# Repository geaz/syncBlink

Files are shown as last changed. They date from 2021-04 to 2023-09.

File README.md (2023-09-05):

   


# syncBlink
**syncBlink** is a lighting system that offers WiFi connectivity, programmability, and responsiveness to music. It enables users to create their own unique light patterns through customizable scripts. To facilitate this, the syncBlink Hub is equipped with a dedicated web application that allows users to write and control these scripts effectively.

In addition, the **syncBlink Hub** initiates a simple mesh network that includes a specialized TCP server. By connecting to this mesh network, **syncBlink Nodes** can establish an additional access point for other nodes to connect to. This means that even if certain nodes are out of range from the **syncBlink Hub**, they can still join the mesh network as long as at least one node is within range. These nodes have the ability to receive messages generated by the hub.

*Combining all these features, it becomes possible to create a synchronized mesh network of WiFi-connected devices that dynamically react to music.*

# State of the Project

This project is considered done. Creating it was a great experience overall. Especially creating the custom script language for the ESP8266 which works pretty great, considering the limitations of the ESP8266. The project implements a complete custom script language, a web application to create, compile and save the scripts, and a VM to execute the compiled scripts. All of this within the available 80kB RAM on the ESP8266.

It still has some flaws (for example the UDP Discovery does not work sometimes) and I still have ideas in mind for this project, but I already spend many hours and days on this project and have to move on. 

# 📖 Table of Contents
1. [🏠 syncBlink Hub](#-syncBlink-Hub)
2. [🌲 syncBlink Node](#-syncBlink-Node)
3. [🚀 Web Application](#-web-application)
4. [🧑‍💻 blinkScript - syncBlink Script Language](#-blinkScript)

## 🏠 syncBlink Hub

The hub is the central part of a **syncBlink** mesh. It provides a web application to manage the mesh and to create and edit **blinkScript**s.

Using the provided 3D models in the *stl* folder, designed in Fusion 360, you can easily bring your **syncBlink Hub** to life. The STL files in the repository make printing the necessary parts a snap. For customizations the Fusion 360 archives files are also provided in the *cad* folder.

The repository tries to provide a clear instruction to give a smooth assembly experience.
Flashing the firmware onto the used Wemos D1 Mini is made simple with using Visual Studio Code and PlatformIO.

Please head over to the **[syncBlink Hub](README%20Station.md)** readme for more information how to build and flash a hub device.

## 🌲 syncBlink Node

The **syncBlink Hub** is just the start. To create a larger mesh of lights it is necessary to build one, two or three nodes (or even more). **syncBlink Nodes** are able to connect to the **syncBlink** mesh to form a larger and wireless light system. The nodes are able to come in any size or form.

Please head over to the **[syncBlink Node](README%20Node.md)** readme for more information how to build and flash your first node device.

## 🚀 Web Application

The **syncBlink Hub** exposes a web application for mobiles and desktop.
Just connect to the access point with the following password:

```
SyncBlinkSaysLetThereBeLight!
```

By visiting the web application on **http://192.168.1.1** with a mobile browser the hub will serve a *setting* page where you are able to configure a WiFi network. The hub will connect to this network during the start procedure.

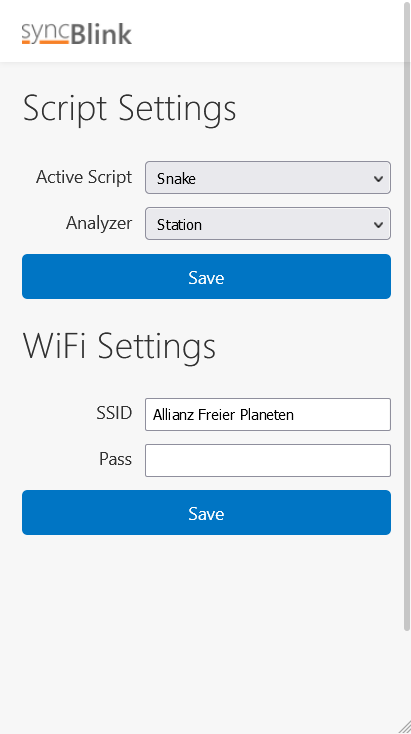
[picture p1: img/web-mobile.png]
syncBlink - Mobile


After the hub is connected to a network the hub IP will appear on the bottom right of the display. By visiting the hub web application with a desktop browser the hub serves an overview of the current **syncBlink Mesh**.

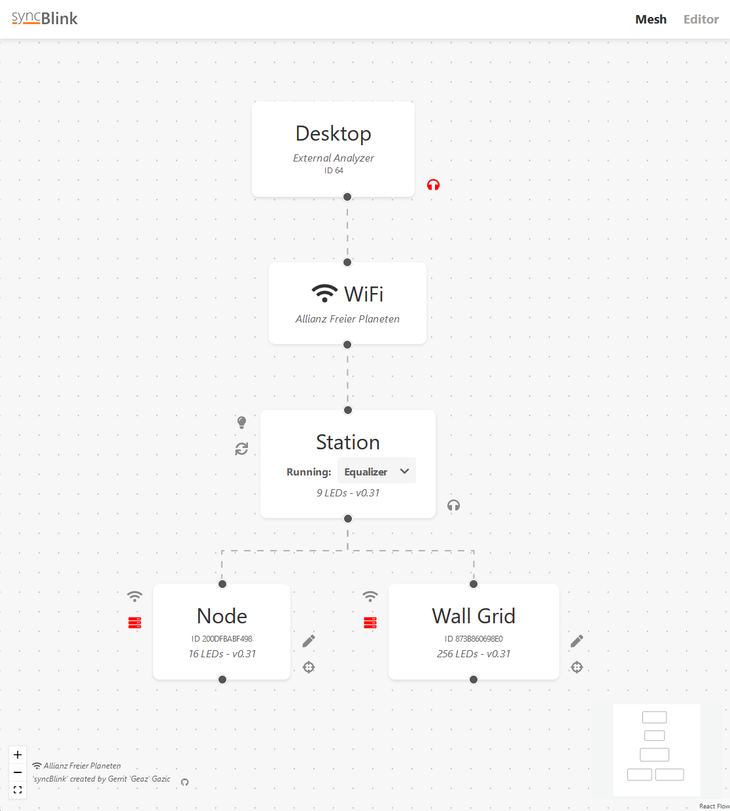
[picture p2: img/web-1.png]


The graph provides functions to a varity of different features. Like pinging nodes, switching the currently running scripts or changing the analyzer. Visit the *Editor* menu to change the content of the scripts on the hub or to create new ones.

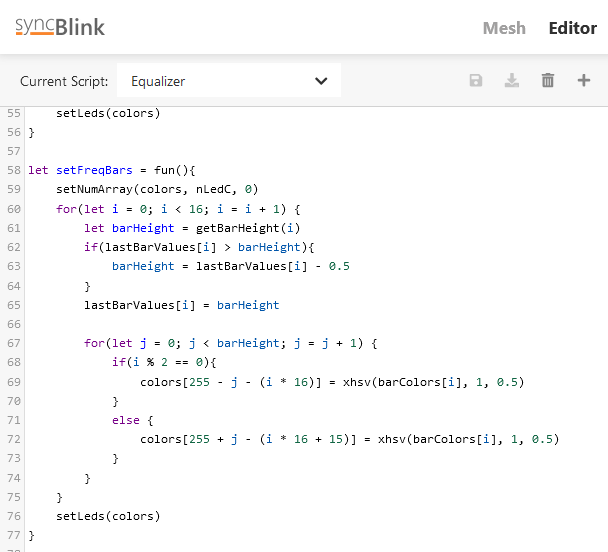
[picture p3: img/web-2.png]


**Info**
```
If you get random disconnections of your nodes after connecting your hub to a WiFi network,  
it is most probably because of an instable connection to the router. The problem is, that the  
ESP8266 just has one WiFi chip which is used to connect to the router AND serves as the access  
point for the nodes. If the hub looses the connection to the router, it can cause a disconnection  
of the access point clients.
```

## 🧑‍💻 blinkScript

**blinkScript** is a custom script language for **syncBlink**. The scripts get compiled by the web application and are stored in a byte code format on the **syncBlink Hub**. On selection the compiled script gets distributed in the mesh and gets execute by the integrated virtual machine on each node.

To make the script language possible on the esp8266 it has a few limitations which shouldn't affect to many scripts (like a limit of 256 objects per script).

The script language is pretty basic and comes with the following features:

- Functions
- Variables
- Conditionals (if/else - NO else if)
- for/while loops
- Arrays
- Closures
- Some build in functions and variables

### Available global variables

- **maxF** *The maximum frequency which is recognizable by syncBlink*
- **nLedC** *The LED count of the current node*
- **mLedC** *The LED count of the whole mesh*
- **pLedC** *The LED count of the current route position*
- **pNodeC** *The node count of the current route position*
- **lVol** *The last analyzed volume in percentage (0-100)*
- **lFreq** *The last analyzed frequency*
- **vol** *The current analyzed volume in percentage (0-100)*
- **freq** *The current analyzed frequency*
- **name** *The name of the current node (initialy specified by the flashed config.json)*
- **type** *The type name of the current node (specified by the flashed config.json)* 
- **freqBin** *An array holding 48 bins of the FFT analysis (power of the different frequencies). The bin resolution is round about 100mHz*       

### Available global functions

- **println(message: string)** *Prints the message to the serial output*
- **setNumArray(array: Array<number>, size: number, value: number)** *Function to quickly fill a numeric array of the given size with the given value. Helpful to reset or initialize an array*
- **setGroups(countPerGroup: number)** *Set the LEDs of the current node to groups of the provided size. For example, if the node has 16 LEDs and setGroups(4) is called, the node will handle the 16 LEDs like four LEDs, where always four LEDs will be grouped together as one.*
- **setLinearGroups(countPerGroup: number)** *Same as above, but the internal numbering of the LEDs will be sequential. Resulting in a different group pattern.*
- **clearGroups()** *Clears all defined groups.*
- **setDelay(analyzerCount: number)** *Delays the analyzer results by the given amount of updates.*
- **getLed(led: number)** *Gets the color (Hex RGB) of the given LED.*
- **setLeds(colors: Array<number>)** *Set LEDs by defining an array of Hex colors.*
- **setAllLeds(color: number)** *Sets all LEDs to the given color (Hex RGB).*
- **map(value: number, inMin: number, inMax: number, outMin: number, outMax: number)** *Maps the value within the range of inMin and inMax to the new range defined by outMin and outMax.*
- **xrgb(r: number, g: number, b: number)** *Converts the given RGB color to a hex number representation.*
- **xhsv(h: number, s: number, v: number)** *Converts the given HSV color to a hex number representation.*

### Minimal example script

Each script has to define two functions as given in the following example.

```
let update = fun(delta) {
    // This function gets executed on each analyzer result (loop)
    // 'delta' contains the milliseconds since the last call of the loop
}

let init = fun(){
    // this function gets executed ONCE at start of the script
}
```

The **syncBlink Hub** comes with some example scripts. Also available [here](src/firmware/data/scripts/).

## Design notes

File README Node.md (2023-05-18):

   


# syncBlink Node
**syncBlink Node**s are devices which are able to connect to the *tcp server* provided by the **syncBlink Hub** or a closer available other *node* via WiFi. Because every *node* is also an access point and a tcp server it is possible to span a pretty big mesh of nodes.

This repository provides a simple example for a **syncBlink Node**. But it is possible to create other devices like for example wall mounted LED devices which will connect to the **syncBlink Hub** to create some nice color effects. Or desk lamp like devices. Just play with your imagination and come up with some cool devices. All you have to do is to take a *Wemos D1 Mini* connect some LEDs and flash the *node* firmware on it.

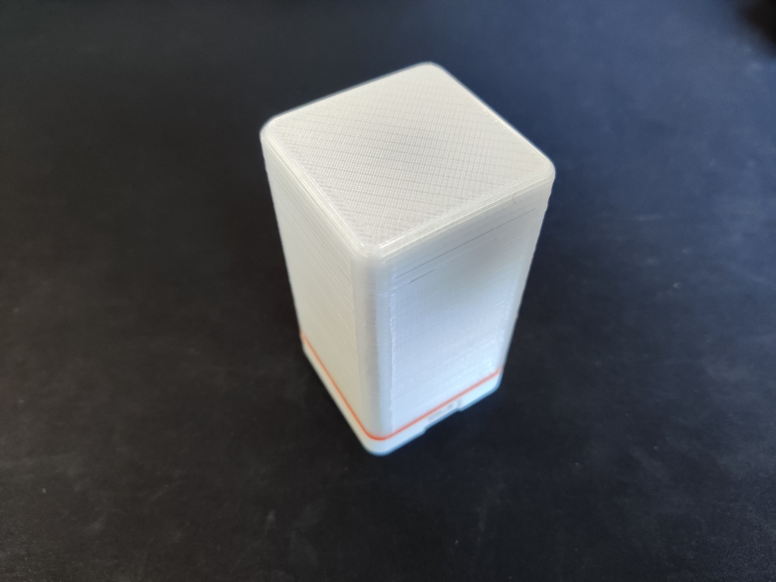
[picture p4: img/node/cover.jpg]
syncBlink - Cover


## BOM

- 3D Printed Parts
- Wemos D1 Mini
- 1x 330 Ohm Resistor
- [4x4 WS2812B LEDs (I used a strip and cut it)](https://www.amazon.de/dp/B01CDTED80)
- 4x M2x12mm screws
- Wire

## Firmware

To flash the firmware onto the Wemos connect it to your PC and press the *Upload* button in the status bar.

syncBlink - Flash

Each node also needs a flashed file system. Primarly to create a *config.json* which contains the configuration for the specific node. Just use the platformIO tasks **Build Filesystem Image** and **Upload Filesystem Image**. PlatformIO will flash the complete content of the *data* folder.

To get a node running the *config.json* needs at least the following content:

```
{
    "name": "Node",   // Initial name of the node (can be changed through the web app)
    "type": "node",   // The type name of the node. Can be used to distinguish nodes in the scripts.
    "led_count": 16,  // Amount of LEDs connected to the node
    "is_node": true   // A flag that tells the firmware, that it runs on a node
}
```

This is the list of all available config keys.

```
{
    "name": "Node",
    "type": "nodeType",
    "led_count": 9,
    "is_hub": false,
    "is_node": true,
    "is_analyzer": false,
    "has_display": false,
    "active_script": "Snake",
    "wifi_ssid": "WIFI",
    "wifi_pw": "PW"
}
```

## Build

Insert the four led strips into the *middle* part. And solder them together - **keep the direction of the data line in mind!**

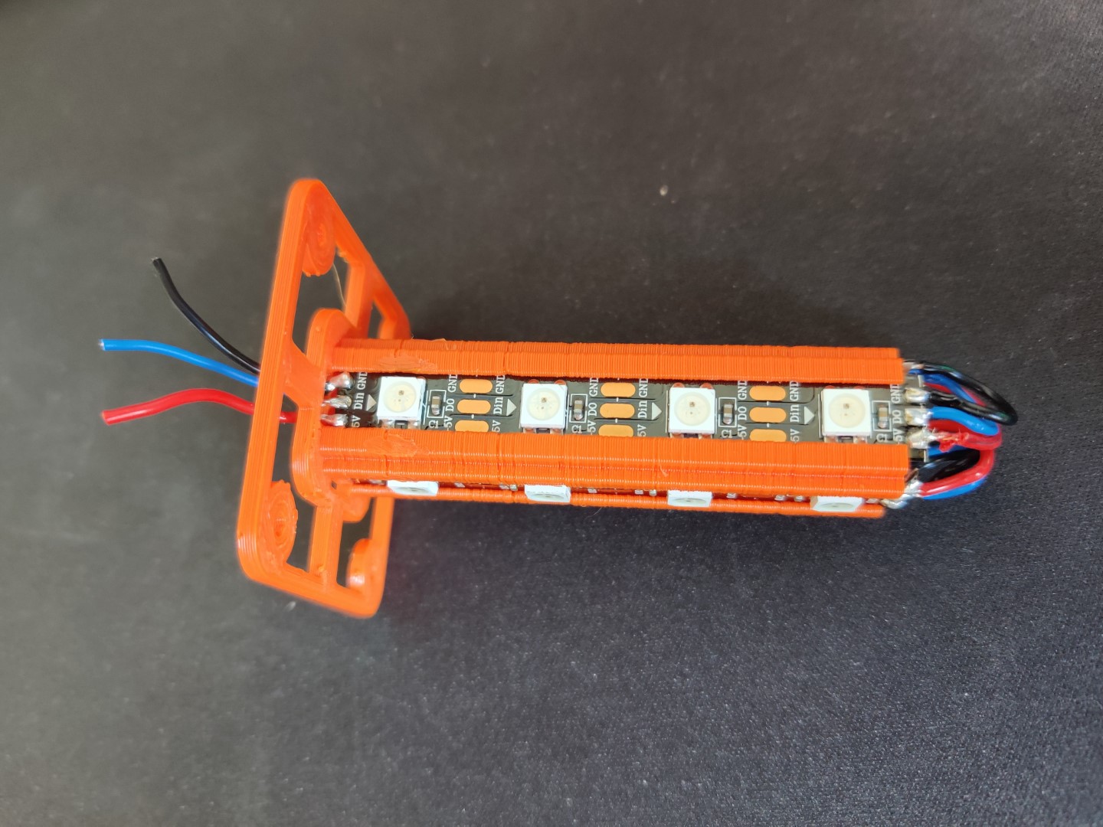
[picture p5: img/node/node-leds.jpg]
node-leds


Solder the LEDs to the *Wemos D1 Mini*. *VCC* to *5V*, *GND* to *GND* and *DataIn* to *D4*. Next, solder the 300Ohm resistor to the pins *RST* and *D0* and insert the *D1 Mini* into the *bottom* part.

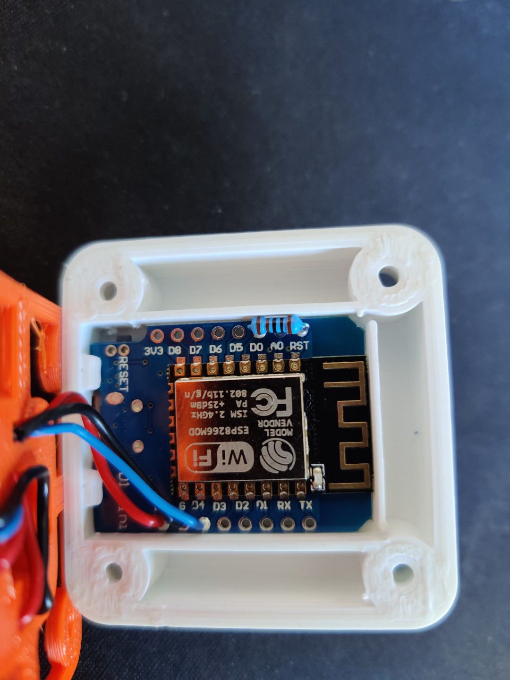
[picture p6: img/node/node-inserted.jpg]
node-inserted


Cut four pieces of paper and insert them into the slots of the *top* part.

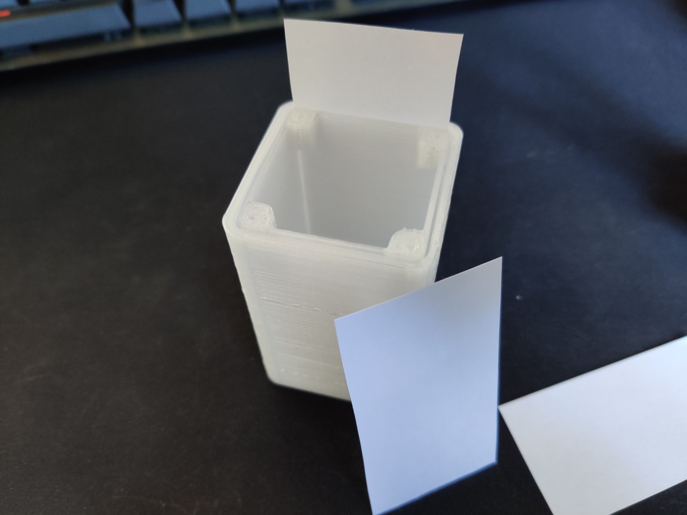
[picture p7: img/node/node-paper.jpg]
node-paper


Now place everything together and close it with the screws. You are done!

node-done

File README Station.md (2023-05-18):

   


# syncBlink Hub

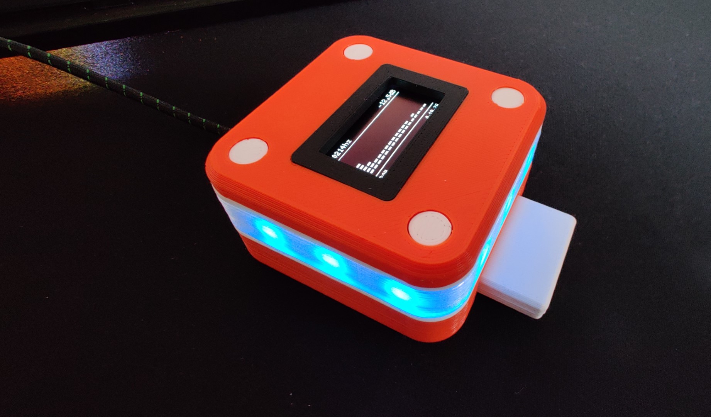
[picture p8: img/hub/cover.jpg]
syncBlink Hub


## Table of Contents
1. [🛥️ 3D Model](#-3d-model)
2. [📄 BOM](#-bom)  
3. [🚀 Firmware](#-firmware)  
4. [👷 Build](#-build)

### 🛥️ 3D Model
The models were designed in Fusion 360. The exported STLs are included in the Github repository (*stl* folder). Furthermore there are Fusion 360 archive files ready to download (*cad* folder).

### 📄 BOM

- 3D Printed Parts
- 1x Wemos D1 Mini
- 1x Capacitor 680uF
- 1x MAX4466
- [9x WS2812B LEDs (I used a strip and cut it)](https://www.amazon.de/dp/B01CDTED80)
- 4x M2x12mm screws
- 4x M3x4mm screws
- Wire
- Hotglue & Superglue

### 🚀 Firmware

Before building **syncBlink** you should flash the firmware onto the Wemos D1 Mini. This way you are able to make sure that it is functional. Open the project in [Visual Studio Code](https://code.visualstudio.com/). The project uses [PlatformIO](https://platformio.org/platformio-ide) to develop the firmware. Install the PlatformIO extension into Visual Studio Code, if not already done. 

To flash the firmware onto the Wemos connect it to your PC and press the *Upload* button in the status bar.

syncBlink - Flash

You also have to flash the file system to the Wemos.

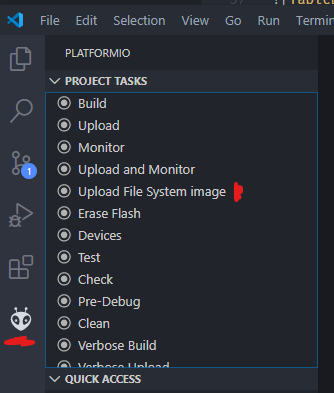
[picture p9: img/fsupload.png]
syncBlink - Filesystem


Afterwards start the *serial monitor* and you should see some outputs like in the screenshot below. If you are able to see the output, the device is working and you are ready to build the **syncBlink Hub**.

syncBlink - Serial

### 👷 Build

First of all, make yourself comfortable with the following schematics. It shows you all parts of the *Hub* which are necessary to connect to each other. We will use a piece of stripboard for each wire which is not directly connected to the Wemos D1 Mini. Mostly to provide power to each part.

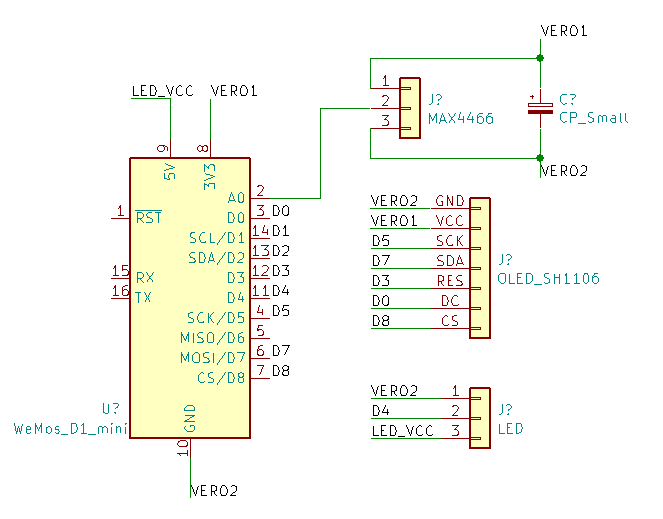
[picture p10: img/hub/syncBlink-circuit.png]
syncBlink - Schematics


Now that you made yourself comfortable with the wiring, take the *Top* part and the *Frame* and glue them together with the superglue. I recommend to place something heavy on top to make sure that they bond well.

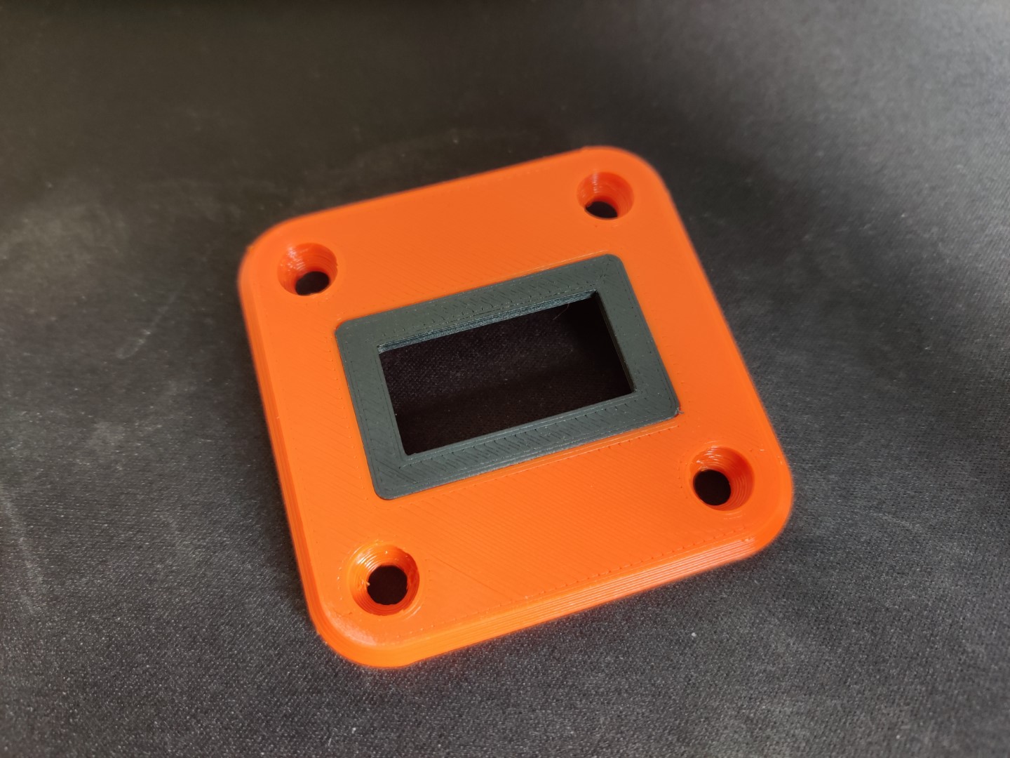
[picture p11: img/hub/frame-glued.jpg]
syncBlink - Frame Glued


Solder wires to your display and mount it to the *Top* part.

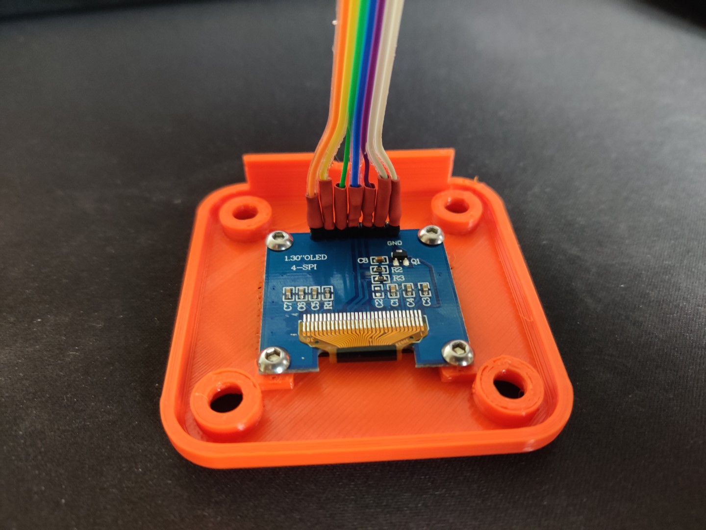
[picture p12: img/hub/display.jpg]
syncBlink - Display


To diffuse the LEDs a bit, the *middle* part has a small slot for a paper insert. Take a bit of paper and cut it into a narrow stripe and insert it into the slot.

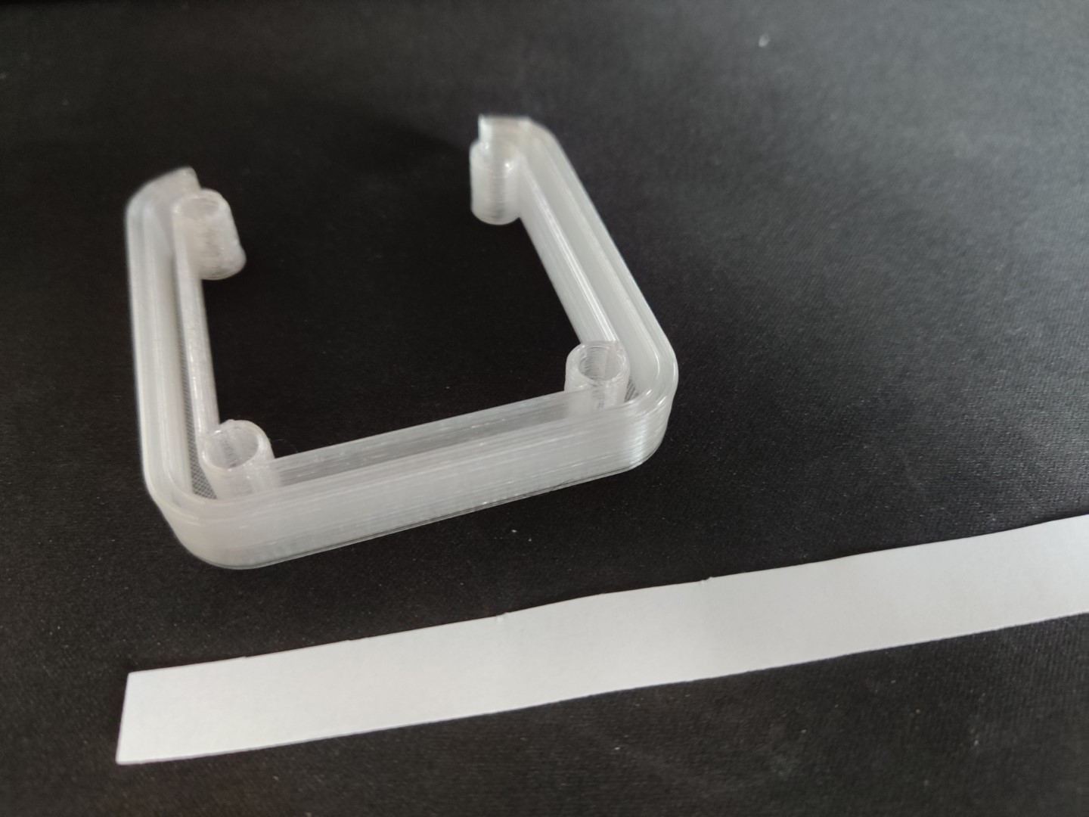
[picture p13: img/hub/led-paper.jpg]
syncBlink - LED Paper


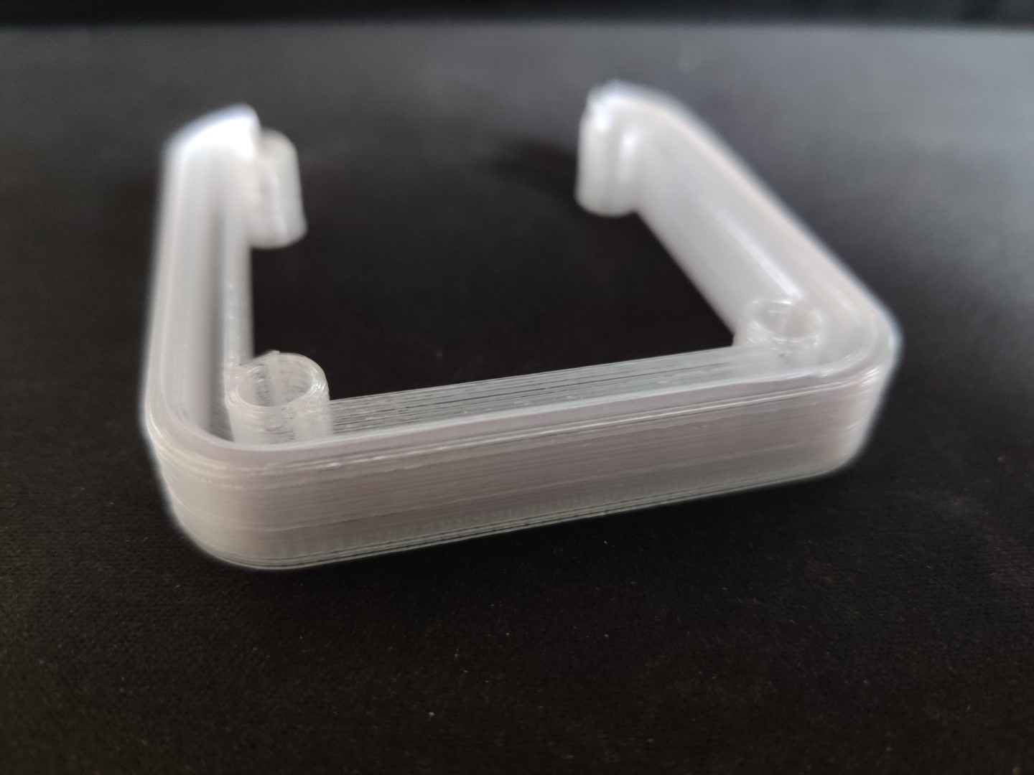
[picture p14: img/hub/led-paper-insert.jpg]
syncBlink - LED Paper Inserted


Solder three wires to your nine LED stripe and insert it into the *middle* part, too - **pay attention to the data line direction**. I bent the cables away from the back of the shell to avoid any possible interference between the microphone cables and the LEDs.

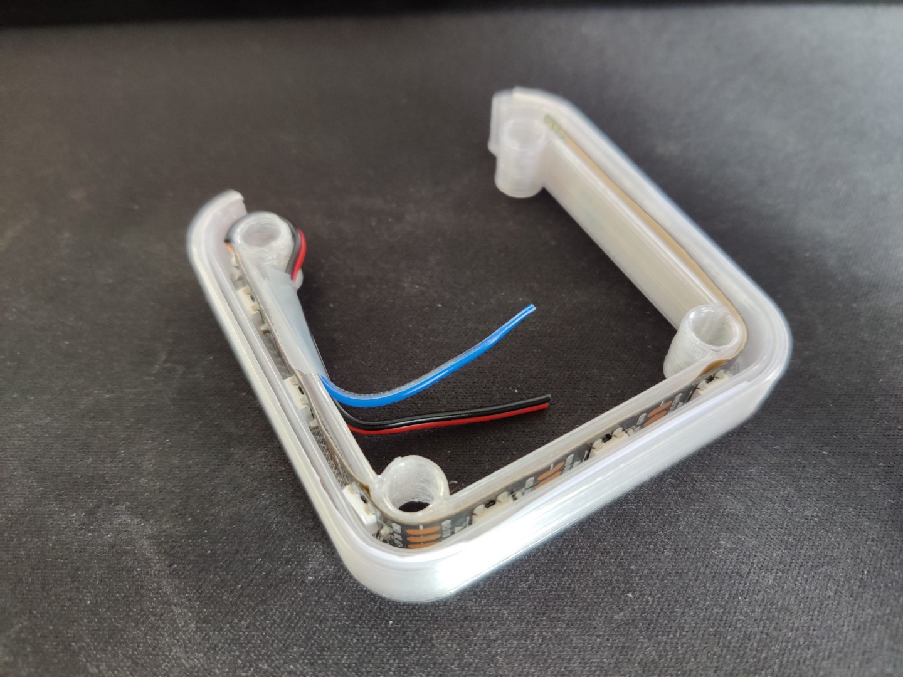
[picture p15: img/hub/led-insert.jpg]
syncBlink - LED Inserted


Solder three wires to your microphone and attach it with hotglue to the *Bottom* part of the shell.

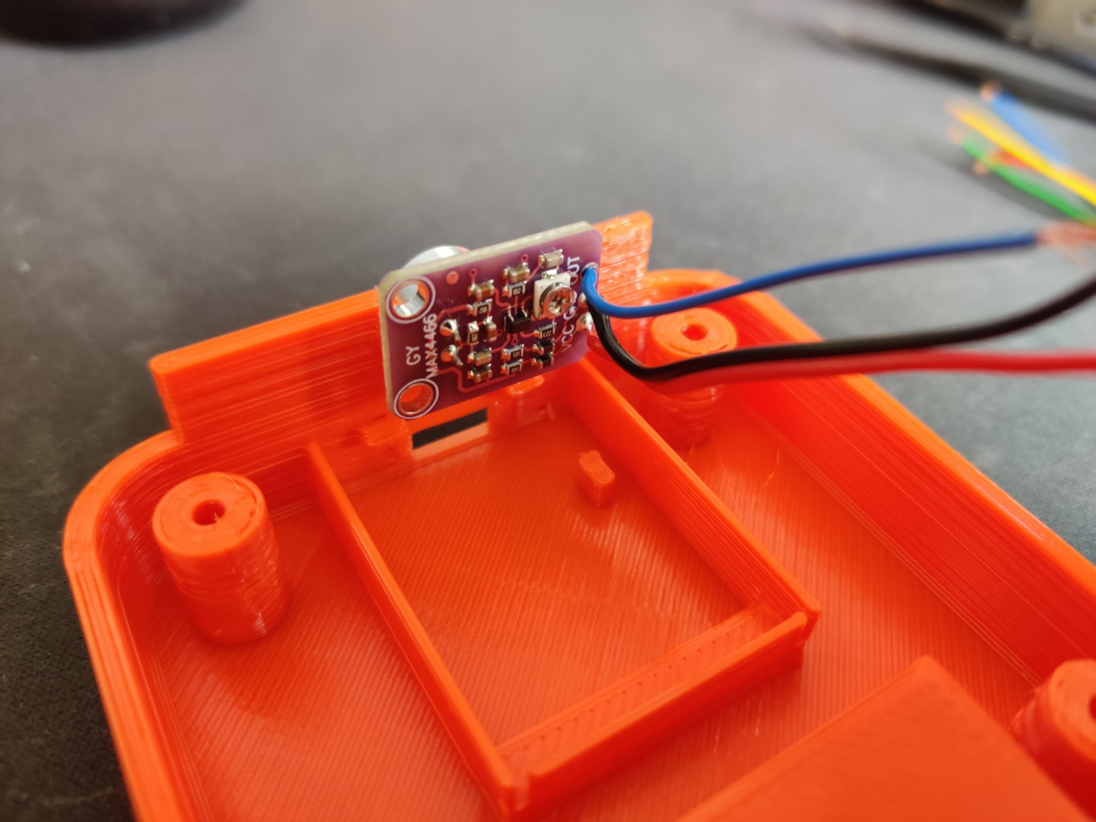
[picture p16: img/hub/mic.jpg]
syncBlink - Mic


Create a 2x7 sized piece out of the stripboard. Picture below as a reference - pay attention to the copper line directions.  
Solder all necessary components and wires as shown in the verboard image below and the schematics above. The ground wires are only indicated (read the red comment) to keep the image tidy.

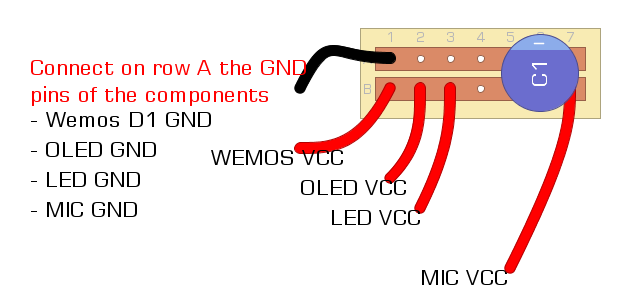
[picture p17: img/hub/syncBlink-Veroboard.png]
syncBlink - Veroboard


Mount the Wemos D1 Mini to the *Bottom* part of the shell.

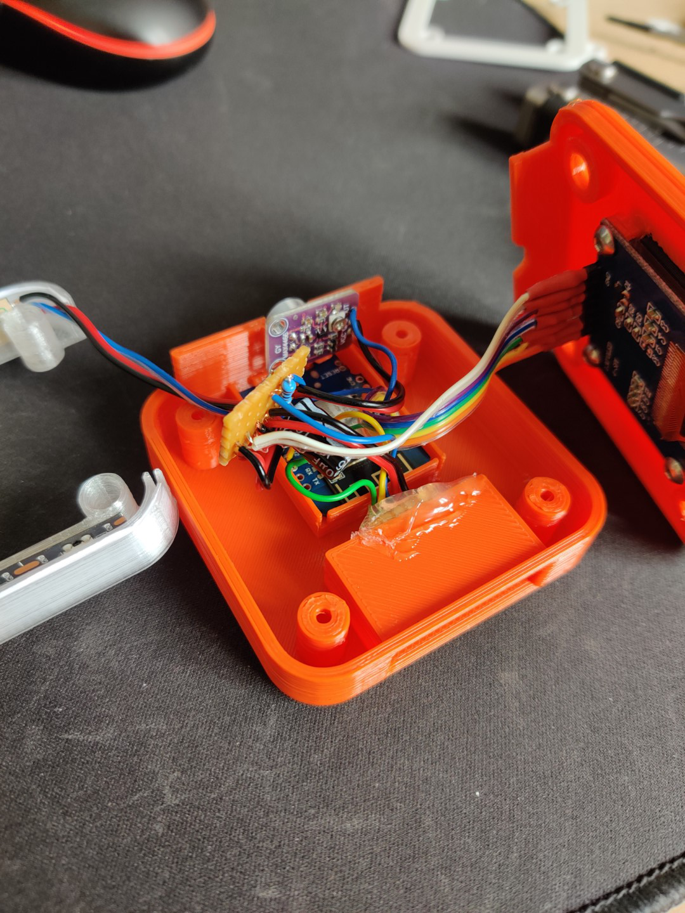
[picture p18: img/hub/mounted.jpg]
syncBlink - Mounted


All components should be connected and you should be able to power the Wemos. You will see the *decibel* in the top right of the display. Set the gain of you microphone with a small screwdriver. It should float between -40 and -43dB in a silent room. If done, place the stripboard into the shell, place one of the *divider* parts on top of the *bottom* part, then place the *middle* part on top of it. Followed by an additional *divider* and the *top* part.
Insert the *bolts* into the four holes and use the M2x12mm screws to close the shell. Your **syncBlink Hub** is done!

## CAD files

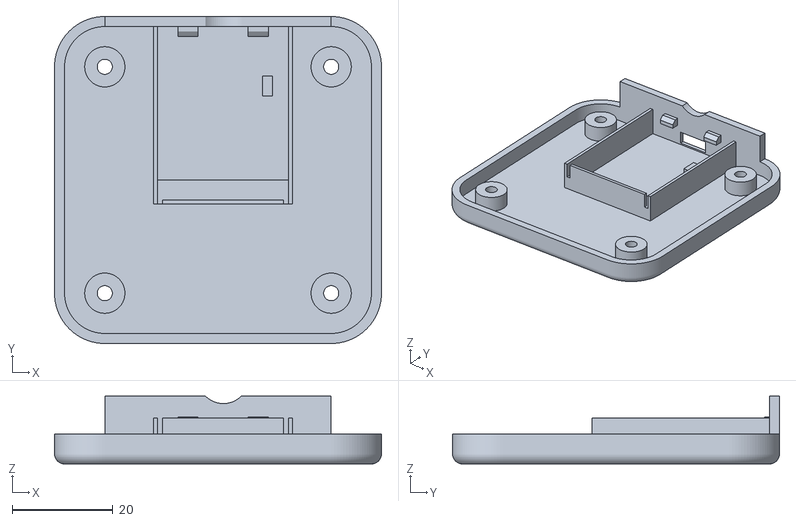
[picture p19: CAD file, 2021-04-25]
stl/hub/1x Bottom.stl
65.0 x 65.0 x 13.5

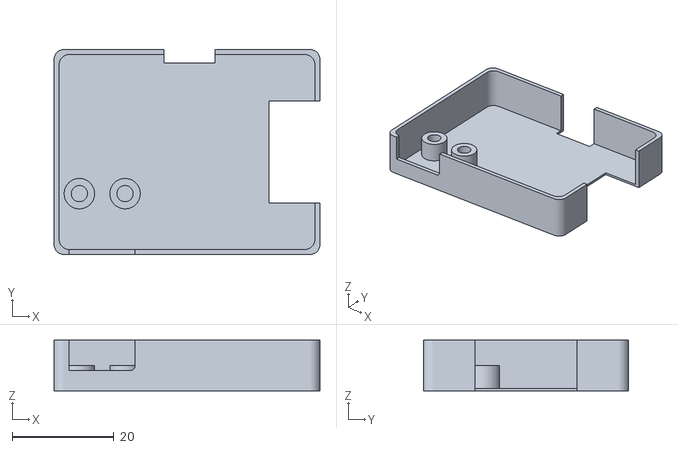
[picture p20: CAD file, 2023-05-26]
stl/matrix/Electronics Bottom (for powerstrips).stl
52.4 x 40.4 x 10.0

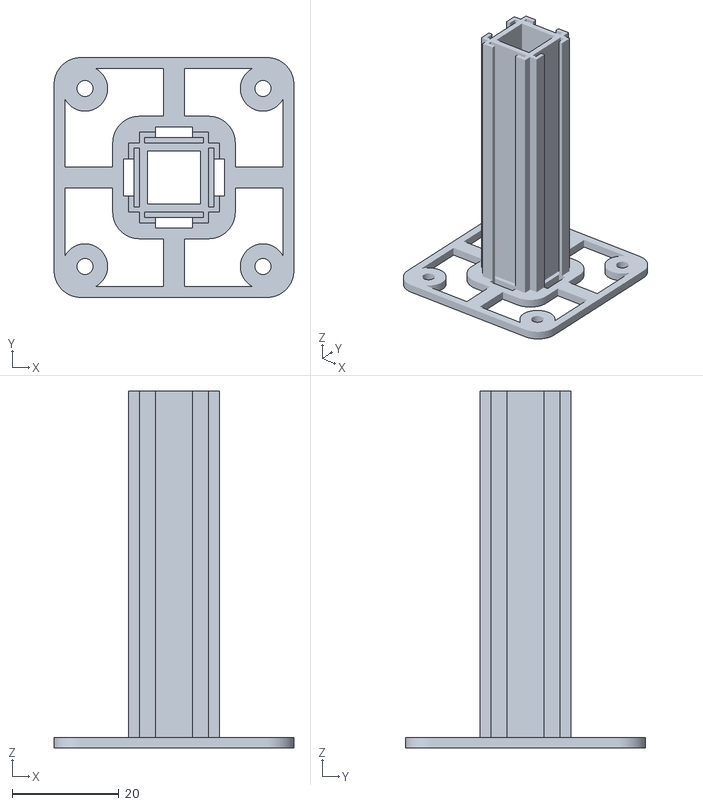
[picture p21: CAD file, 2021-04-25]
stl/node/Middle.stl
45.0 x 45.0 x 67.0

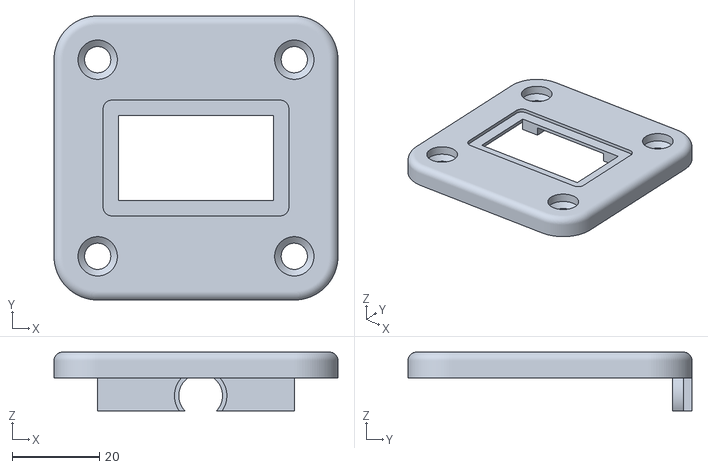
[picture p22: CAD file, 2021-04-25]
stl/hub/1x Top.stl
65.0 x 65.0 x 13.5

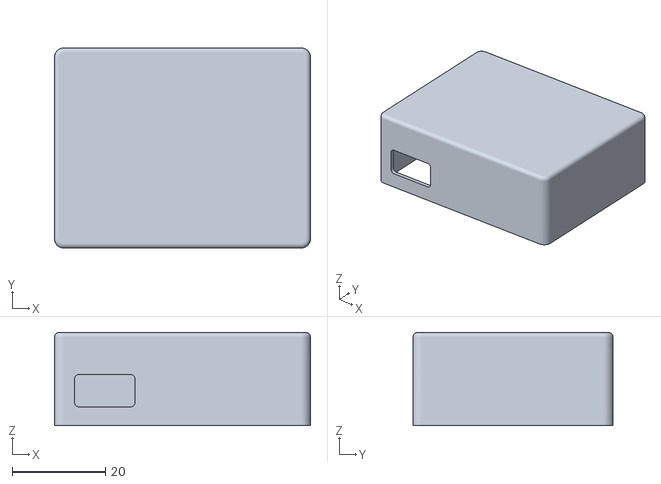
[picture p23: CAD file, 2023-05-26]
stl/matrix/Electronics Top.stl
55.0 x 43.0 x 20.0

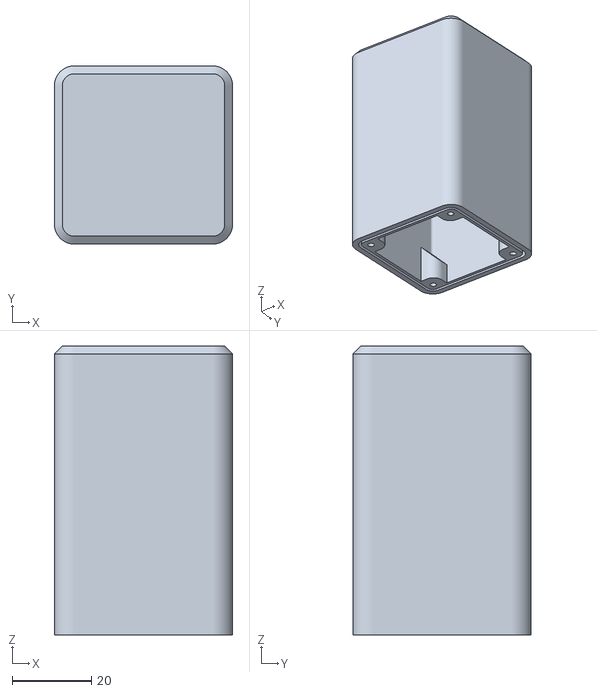
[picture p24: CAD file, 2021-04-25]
stl/node/Top.stl
45.0 x 45.0 x 73.0

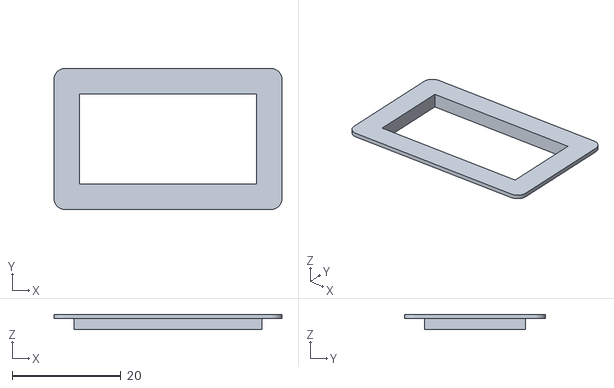
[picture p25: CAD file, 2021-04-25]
stl/hub/1x Frame.stl
41.9 x 25.9 x 2.80

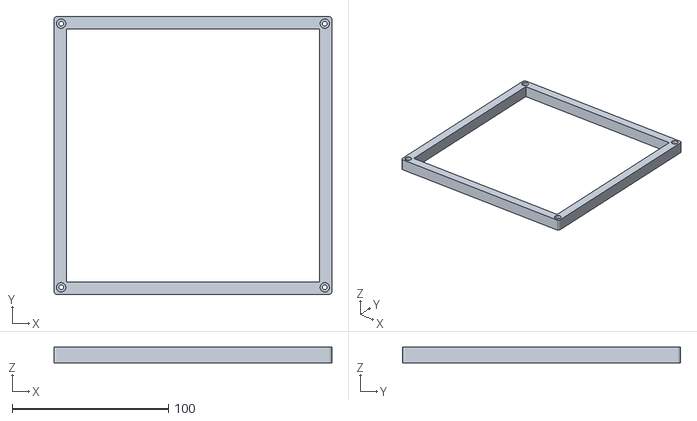
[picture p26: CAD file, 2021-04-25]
stl/matrix/Frame.stl
177.8 x 177.8 x 10.2

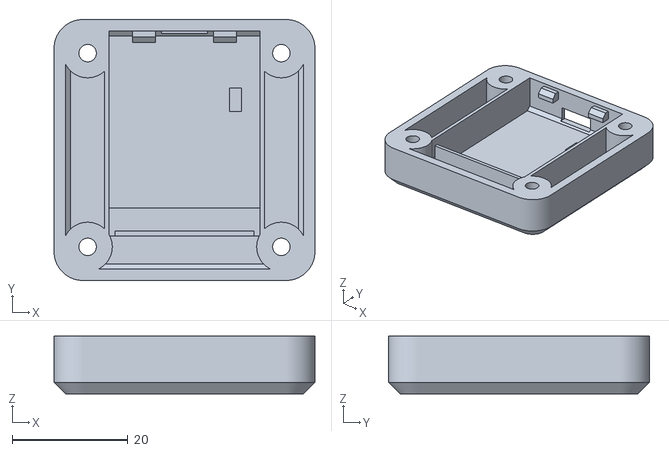
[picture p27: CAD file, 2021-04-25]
stl/node/Bottom.stl
45.0 x 45.0 x 10.0

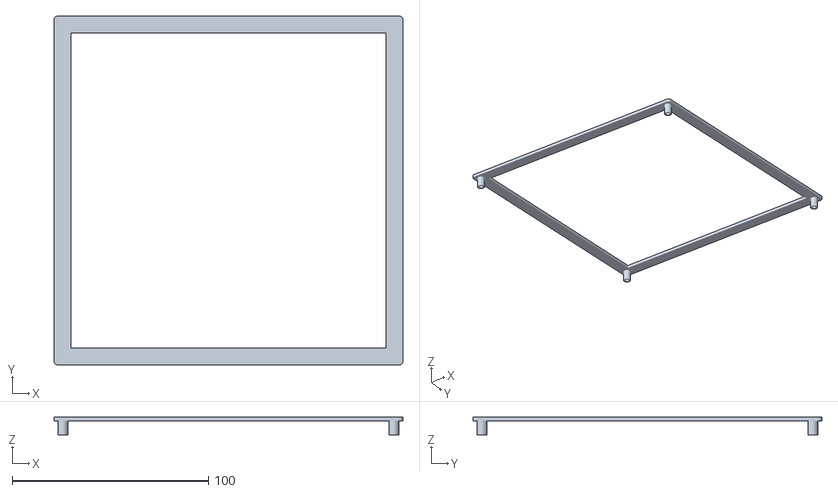
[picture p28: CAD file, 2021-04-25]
stl/matrix/Frame Top.stl
177.8 x 177.8 x 9.00

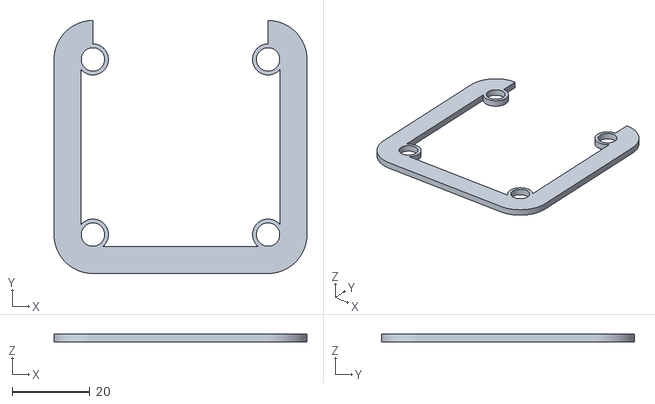
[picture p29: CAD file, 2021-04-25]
stl/hub/2x Divider.stl
65.0 x 65.0 x 2.00

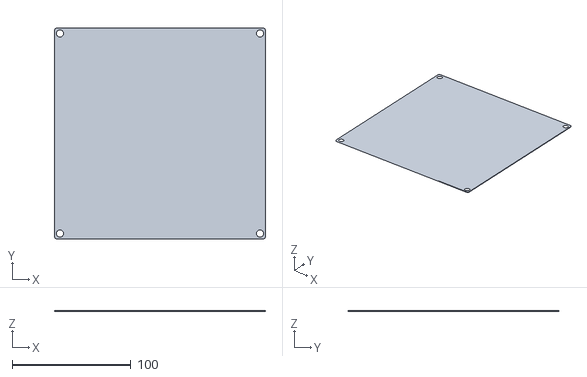
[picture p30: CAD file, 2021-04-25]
stl/matrix/Diffusor.stl
177.8 x 177.8 x 0.6

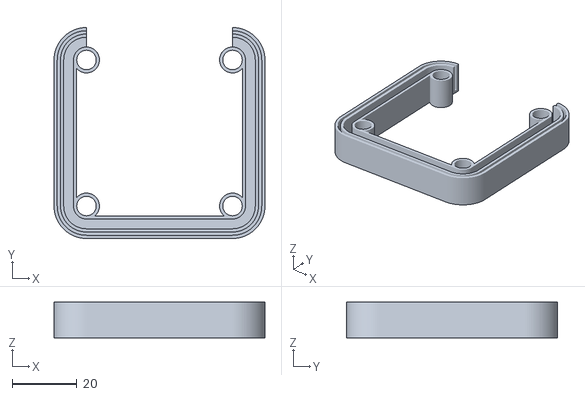
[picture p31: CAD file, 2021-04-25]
stl/hub/1x Middle.stl
65.0 x 65.0 x 11.0

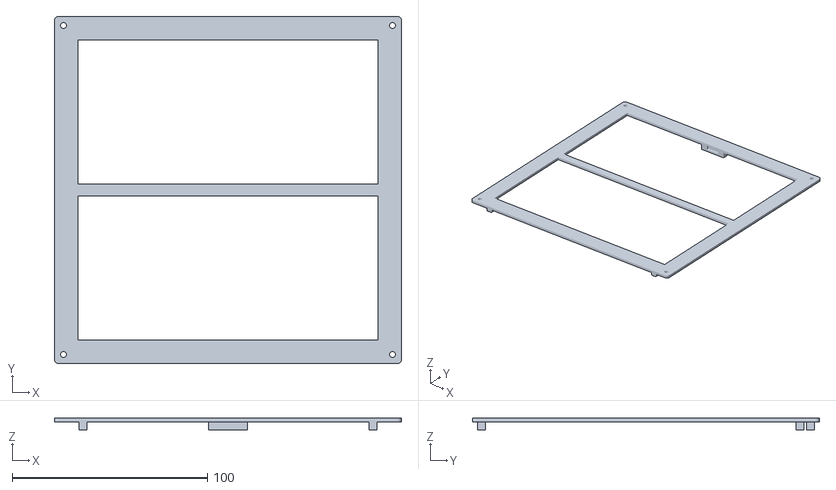
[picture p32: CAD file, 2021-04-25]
stl/matrix/Back.stl
177.8 x 177.8 x 6.00

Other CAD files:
stl/matrix/PixelGrid.stl
stl/hub/4x Bolt.stl
cad/syncBlink Node.f3d
cad/syncBlink-Station.f3z

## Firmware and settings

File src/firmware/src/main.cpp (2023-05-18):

#include "core/script_list.hpp"
#include "core/mesh_info.hpp"
#include "core/config/config.hpp"
#include "core/message/message_bus.hpp"
#include "modules/analyzer_module.hpp"
#include "modules/blinkscript_module.hpp"
#include "modules/display_module.hpp"
#include "modules/hub_wifi_module.hpp"
#include "modules/node_wifi_module.hpp"
#include "modules/script_broadcast_module.hpp"
#include "modules/web_module.hpp"

#include <LittleFS.h>
#include <Wire.h>
#include <led.hpp>
#include <vector>

SyncBlink::LED led;
SyncBlink::Config config;
SyncBlink::ScriptList scriptList;
SyncBlink::MeshInfo meshInfo(config, scriptList);
SyncBlink::MessageBus messageBus;
std::vector<std::shared_ptr<SyncBlink::Module>> modules;

#ifdef LOG_HEAP
long lastHeapLog;
#endif

void setup()
{
    Serial.begin(74880);
    LittleFS.begin();

    pinMode(LED_PIN, OUTPUT);
    pinMode(A0, INPUT);

    config.load();
    led.setup(config.Values[F("led_count")]);

    if (config.Values[F("is_hub")])
    {
        Serial.println(F("[MAIN] Starting Hub mode ..."));

        modules.push_back(std::make_shared<SyncBlink::AnalyzerModule>(messageBus, meshInfo));
        modules.push_back(std::make_shared<SyncBlink::DisplayModule>(messageBus));
        modules.push_back(std::make_shared<SyncBlink::ScriptBroadcastModule>(messageBus, meshInfo, scriptList));
        modules.push_back(std::make_shared<SyncBlink::HubWifiModule>(config, messageBus, scriptList, meshInfo));
        modules.push_back(std::make_shared<SyncBlink::BlinkScriptModule>(led, messageBus, scriptList, config.Values[F("name")], config.Values[F("type")]));
        modules.push_back(std::make_shared<SyncBlink::WebModule>(messageBus, config, scriptList, meshInfo));
    }
    else
    {
        if (config.Values[F("is_analyzer")])
        {
            Serial.println(F("[MAIN] Adding Analyzer Module ..."));
            modules.push_back(std::make_shared<SyncBlink::AnalyzerModule>(messageBus, meshInfo));
        }

        if (config.Values[F("has_display")])
        {
            Serial.println(F("[MAIN] Adding Display Module ..."));
            modules.push_back(std::make_shared<SyncBlink::DisplayModule>(messageBus));
        }

        if (config.Values[F("is_node")])
        {
            Serial.println(F("[MAIN] Starting Node mode ..."));
            modules.push_back(std::make_shared<SyncBlink::NodeWifiModule>(config, led, messageBus, scriptList, meshInfo));
            modules.push_back(std::make_shared<SyncBlink::BlinkScriptModule>(led, messageBus, scriptList, config.Values[F("name")], config.Values[F("type")]));
        }
    }

    for (auto module : modules)
    {
        module->setup();
    }
}

void loop()
{
    for (auto module : modules)
    {
        module->loop();
    }
    led.loop();

#ifdef LOG_HEAP
    if (millis() - lastHeapLog > 1000)
    {
        Serial.printf_P(PSTR("DRAM free: %6d bytes\r\n"), ESP.getFreeHeap());
        lastHeapLog = millis();
    }
#endif
}

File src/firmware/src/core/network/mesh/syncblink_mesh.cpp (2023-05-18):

#include "syncblink_mesh.hpp"

namespace SyncBlink
{
    SyncBlinkMesh::SyncBlinkMesh(const char* wifiSsid, const char* wifiPw) : _wifiSsid(wifiSsid), _wifiPw(wifiPw)
    {
        WiFi.disconnect();
        WiFi.mode(WIFI_AP_STA);
        WiFi.setSleepMode(WIFI_NONE_SLEEP);
    }

    void SyncBlinkMesh::connectWifi()
    {
        if (_wifiSsid != nullptr)
        {
            Serial.println("[WIFI] Connecting to Network '" + String(_wifiSsid) + "'  ...");
            WiFi.begin(_wifiSsid, _wifiPw);

            Serial.println(F("[WIFI] Waiting for Wifi to connect (30 sec timeout)..."));
            if (WiFi.waitForConnectResult(30000) == WL_CONNECTED)
            {
                Serial.println(F("[WIFI] Connected!"));
            }
            else
            {
                Serial.println(F("[WIFI] Couldn't connect to network!"));
                WiFi.disconnect();
            }
        }
    }

    void SyncBlinkMesh::startMesh()
    {
        Serial.println(F("[WIFI] Starting mesh ..."));

        _ssid = SSID + " #1";
        WiFi.softAPConfig(IPAddress(192, 168, 1, 1), IPAddress(0, 0, 0, 0), IPAddress(255, 255, 255, 0));
        WiFi.softAP(_ssid, Password, 1, false, 8);

        _localIp = WiFi.localIP();
        Serial.println("[WIFI] Node AP IP: " + WiFi.softAPIP().toString());
        Serial.println("[WIFI] Node Local IP: " + WiFi.localIP().toString());
    }

    bool SyncBlinkMesh::tryJoinMesh()
    {
        bool connected = WiFi.isConnected();
        if (connected)
        {
            Serial.println(F("[WIFI] Node is connected to mesh via WiFi network."));
            Serial.println(F("[WIFI] Searching for available hubs ..."));

            _connectedToMeshWiFi = false;
            _udpDiscover.start(false);
            uint64_t start = millis();
            while (!_udpDiscover.serverDiscovered(_parentIp) && start + 5000 > millis())
            {
                _udpDiscover.ping();
                delay(500);
                _udpDiscover.loop();
            }
            _udpDiscover.stop();
        }
        else
        {
            Serial.println(F("[WIFI] Scanning for SyncBlink Nodes ..."));
            uint8_t foundSyncblinkNetworks = 0;
            uint8_t foundNetworkCount = WiFi.scanNetworks();

            uint8_t nodeNr = 1;
            uint8_t highestNodeNr = 0;
            int8_t connectToNode = -1;

            for (int i = 0; i < foundNetworkCount; ++i)
            {
                if (WiFi.SSID(i).startsWith(SSID))
                {
                    foundSyncblinkNetworks++;

                    String ssid = WiFi.SSID(i);
                    short foundNodeNr = ssid.substring(ssid.indexOf("#") + 1).toInt();

                    // We seek for an evenly distributed mesh
                    // Thats why we always connect to the "highest node number", if we found
                    // more than two nodes in range.
                    if (connectToNode == -1 || (foundSyncblinkNetworks > 2 && foundNodeNr > highestNodeNr)) connectToNode = i;

                    if (foundNodeNr > highestNodeNr) highestNodeNr = foundNodeNr;
                    if (foundNodeNr >= nodeNr) nodeNr = foundNodeNr + 1;
                }
            }

            if (connectToNode != -1)
            {
                Serial.println("[WIFI] Connecting to '" + WiFi.SSID(connectToNode) + "' (30 sec Timeout)...");
                WiFi.begin(WiFi.SSID(connectToNode), Password);

                if (WiFi.waitForConnectResult(30000) == WL_CONNECTED)
                {
                    Serial.println(F("[WIFI] Connected!"));

                    _ssid = SSID + " #" + String(nodeNr);

                    WiFi.softAPConfig(IPAddress(192, 168, nodeNr, 1), IPAddress(0, 0, 0, 0), IPAddress(255, 255, 255, 0));
                    WiFi.softAP(_ssid, Password, 1, false, 8);
                    WiFi.setAutoReconnect(false);

                    Serial.println("[WIFI] Node AP IP: " + WiFi.softAPIP().toString());
                    Serial.println("[WIFI] Node Local IP: " + WiFi.localIP().toString());
                    connected = true;

                    _parentIp = WiFi.gatewayIP();
                    _localIp = WiFi.localIP();
                }
            }
        }
        return connected;
    }

    bool SyncBlinkMesh::isConnected() const
    {
        return WiFi.isConnected();
    }

    bool SyncBlinkMesh::isConnectedToMeshWifi() const
    {
        return _connectedToMeshWiFi;
    }

    bool SyncBlinkMesh::hasConnectedNodes() const
    {
        return WiFi.softAPgetStationNum() != 0;
    }

    IPAddress SyncBlinkMesh::getParentIp() const
    {
        return _parentIp;
    }

    IPAddress SyncBlinkMesh::getLocalIp() const
    {
        return _localIp;
    }
}

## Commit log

2021-04-25 First arduino mono repo checkin
    [1x Bottom.stl, 1x Frame.stl, 1x Middle.stl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]
2021-04-25 Fixed led count
2021-04-25 Add Matrix STLs
    [Back.stl, Diffusor.stl, Frame Top.stl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]
2021-04-26 Store LED_COUNT in EEPROM
2021-04-27 Reworked Socket Connection and add firmware updater
2021-05-06 Two mesh connection fixes
    [syncblink_mesh.cpp]
2021-07-22 Feature node analyzers (#2)
    * Add node analyzers
    * Add light mode
    * Minor fixes
    * Update web app
    * Update syncblink_mesh.cpp
    [main.cpp, syncblink_mesh.cpp]
2021-10-09 Add fixed Framework version
2023-05-18 Huge rewrite (#4)
    * First Restructure Commit
    * First Runnable Version on single Hub
    * Format
    * Update fail_safe_state.cpp
    * Add AnalyzerMode
    HubMode and NodeMode are now inheriting from AnalyzerMode.
    AnalyzerMode now sends AnalyzerResultEvents. RunScriptState does not run the frequency analyzer on its own anymore.
    * Format changes
    * Change to module system
    * Move Code
    * Module refactoring
    * Renaming events to messages
    e
    * Rewrite Message and Message Packages
    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
    [1x Bottom.stl, 1x Frame.stl, 1x Middle.stl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]
2023-05-26 Add electronics box for matrix
    [Electronics Bottom (for powerstrips).stl, Electronics Top.stl]
